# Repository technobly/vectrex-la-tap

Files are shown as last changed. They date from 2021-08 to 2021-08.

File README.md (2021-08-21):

Vectrex LA TAP
===

The Vectrex LA Tap is a logic analyzer tap for the Vectrex. It also turns the cartridge to face the player.  Use it for technical debugging, or just as a way to display your running cartridge. Populate either the right-angle or straight male header for connections, or both.  I prefer the right-angle to keep the jumpers lower to the table where your logic analyzer is located.  This can also be used as a quick way to add RAM to a game if you don't have a multicart like [VEXTREME](https://github.com/technobly/VEXTREME) that can do that for you programmatically.

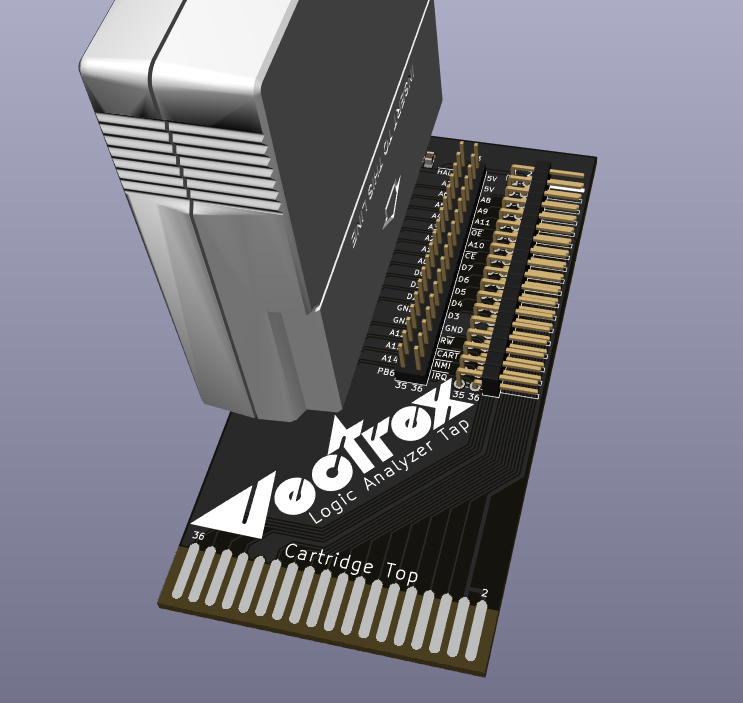
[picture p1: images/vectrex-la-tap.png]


See it in action here:
https://www.youtube.com/watch?v=Tel6ZxioI6E

BOM and Parts ordering
===

- 1x - 36-pin Edge Connector [AMP 5645235-4](https://www.digikey.com/en/products/detail/te-connectivity-amp-connectors/5645235-4/1122061)

Optional Components
- 1x - 36-pin 2.54 mm dual-row right-angle male header [PH2RA-36-UA](https://www.digikey.com/en/products/detail/adam-tech/PH2RA-36-UA/9830520)
- 1x - 36-pin 2.54 mm dual-row straight male header [PRPC018DAAN-RC](https://www.digikey.com/en/products/detail/sullins-connector-solutions/PRPC018DAAN-RC/2775276)
- 1x - [0.1uF 0805 capacitor](https://www.digikey.com/en/products/detail/avx-corporation/08055C104KAT2A/563505)

Ordering PCB's
===

OSHPark is a good place to order with purple or the new "after dark" theme color scheme.  You can upload the KiCad `vextrex-la-tap.kicad_pcb` there directly.  I would download this entire Github repo ZIP file first though instead of just trying to save the PCB file from your browser.

Another way to order PCB's is by using the included [gerbers](gerbers/vectrex-la-tap-v1.0.zip) and uploading those with all of the necessary specs to companies like [PCBWay](https://www.pcbway.com) or [JLCPCB](https://jlcpcb.com)

If you want to make it fancy, don't forget to make your board finish ENIG (gold flash) with a 45 degree chamfered edge.  I ended up making these really cheap with HASL finish since I won't be using them that frequently.

LICENSE
===

Creative Commons Attribution-ShareAlike 4.0 International (CC BY-SA 4.0) - essentially do whatever you want, and if this is helpful to you [consider buying me a coffee](https://buymeacoffee.com/walach)  Full [LICENSE here](LICENSE)

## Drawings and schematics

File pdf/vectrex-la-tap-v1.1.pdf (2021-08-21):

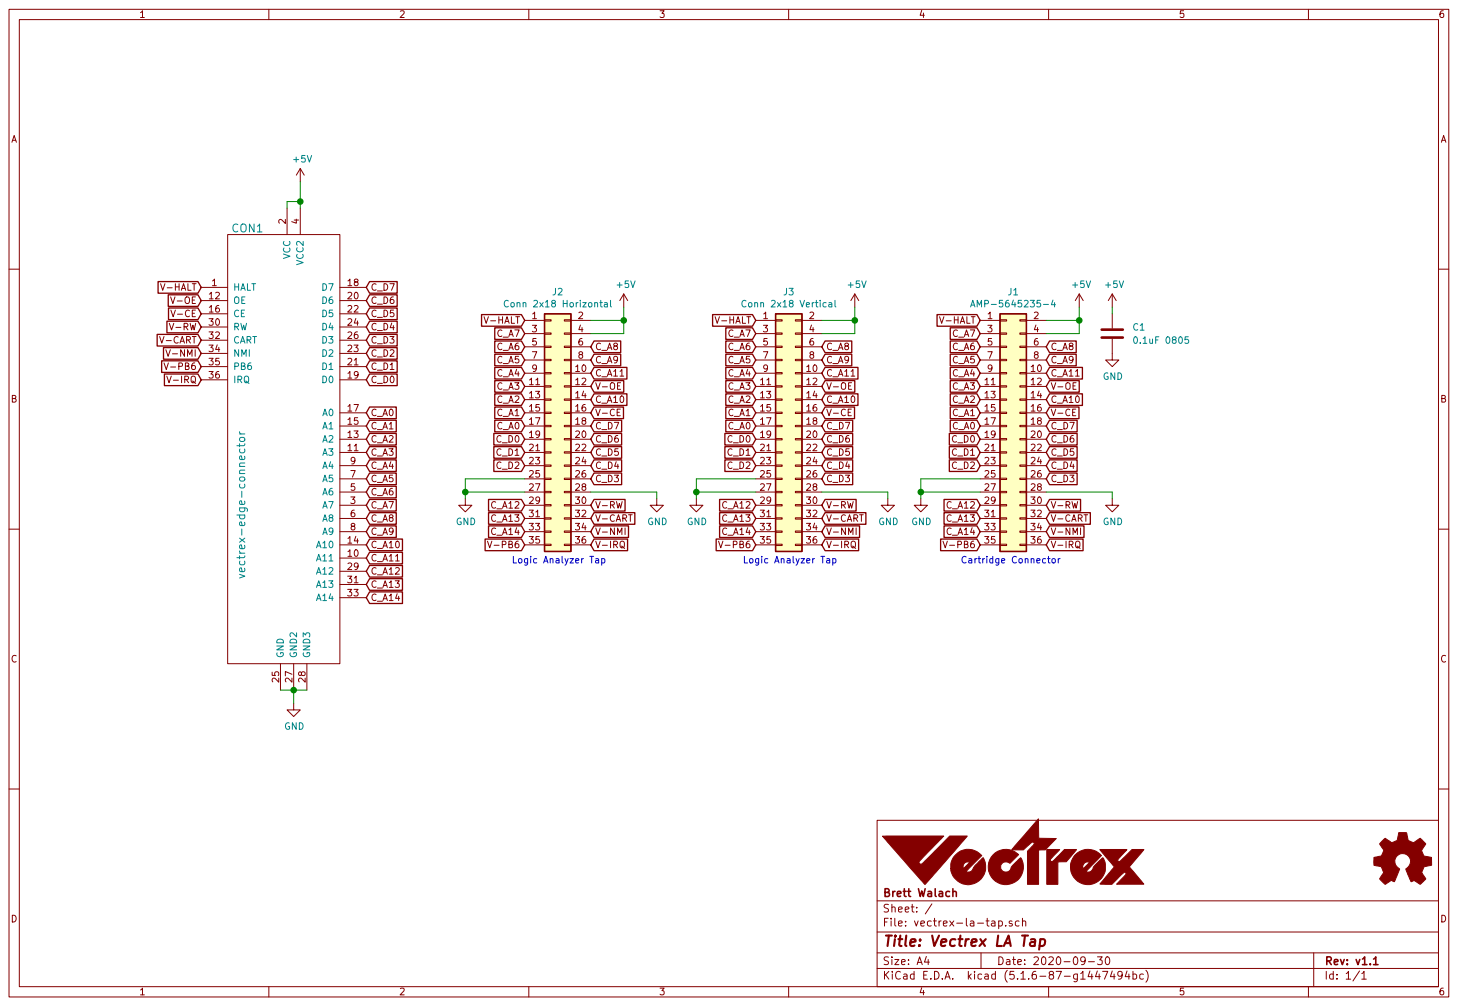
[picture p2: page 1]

4 A6 5 A8 6 A5 7 A9 8 A4 9 A11 10 D6 20 RW 30 A3 11 D1 21 A13 31 OE 12 D5 22 CART 32 A2 13 D2 23 A14 33 A10 14 D4 24 NMI 34 A1 15 GND 25 PB6 35 CE 16 D3 26

Id: 1/1 Title: Vectrex LA Tap

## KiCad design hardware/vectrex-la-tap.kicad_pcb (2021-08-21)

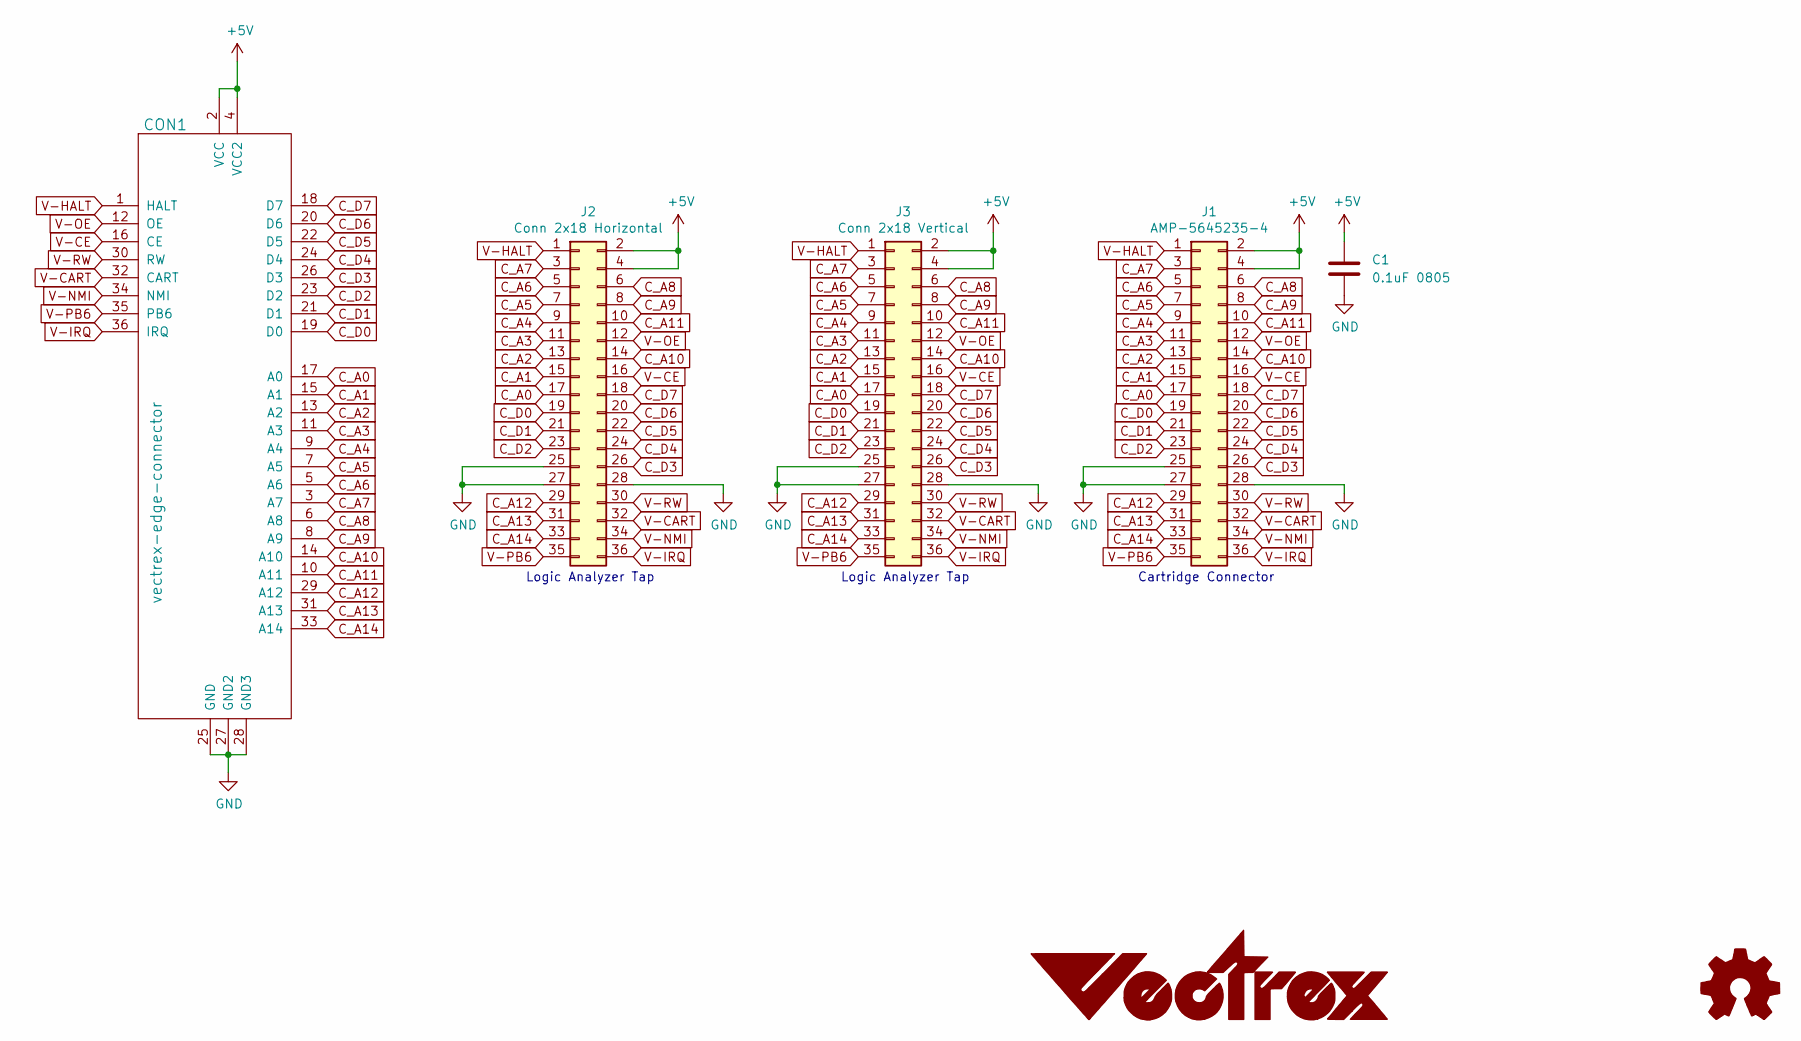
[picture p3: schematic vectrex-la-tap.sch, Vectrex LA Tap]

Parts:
C1: 0.1uF 0805; C_0805_2012Metric_Pad1.15x1.40mm_HandSolder
CON1: vectrex-edge-connector; vectrex-edge-connector-thinner-no-soldermask
G1: LOGO; vectrex-us-silkscreen
J1: AMP-5645235-4; AMP_5645235-4_2x18_P2.54mm_Vertical
J2: Conn 2x18 Horizontal; PinHeader_2x18_P2.54mm_Horizontal
J3: Conn 2x18 Vertical; PinHeader_2x18_P2.54mm_Vertical

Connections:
+5V: C1.1, CON1.2 (VCC), CON1.4 (VCC2), J1.2, J1.4, J2.2, J2.4, J3.2, J3.4
C_A0: CON1.17 (A0), J1.17, J2.17, J3.17
C_A1: CON1.15 (A1), J1.15, J2.15, J3.15
C_A2: CON1.13 (A2), J1.13, J2.13, J3.13
C_A3: CON1.11 (A3), J1.11, J2.11, J3.11
C_A4: CON1.9 (A4), J1.9, J2.9, J3.9
C_A5: CON1.7 (A5), J1.7, J2.7, J3.7
C_A6: CON1.5 (A6), J1.5, J2.5, J3.5
C_A7: CON1.3 (A7), J1.3, J2.3, J3.3
C_A8: CON1.6 (A8), J1.6, J2.6, J3.6
C_A9: CON1.8 (A9), J1.8, J2.8, J3.8
C_A10: CON1.14 (A10), J1.14, J2.14, J3.14
C_A11: CON1.10 (A11), J1.10, J2.10, J3.10
C_A12: CON1.29 (A12), J1.29, J2.29, J3.29
C_A13: CON1.31 (A13), J1.31, J2.31, J3.31
C_A14: CON1.33 (A14), J1.33, J2.33, J3.33
C_D0: CON1.19 (D0), J1.19, J2.19, J3.19
C_D1: CON1.21 (D1), J1.21, J2.21, J3.21
C_D2: CON1.23 (D2), J1.23, J2.23, J3.23
C_D3: CON1.26 (D3), J1.26, J2.26, J3.26
C_D4: CON1.24 (D4), J1.24, J2.24, J3.24
C_D5: CON1.22 (D5), J1.22, J2.22, J3.22
C_D6: CON1.20 (D6), J1.20, J2.20, J3.20
C_D7: CON1.18 (D7), J1.18, J2.18, J3.18
GND: C1.2, CON1.25 (GND), CON1.27 (GND2), CON1.28 (GND3), J1.25, J1.27, J1.28, J2.25, J2.27, J2.28, J3.25, J3.27, J3.28
V-CART: CON1.32 (CART), J1.32, J2.32, J3.32
V-CE: CON1.16 (CE), J1.16, J2.16, J3.16
V-HALT: CON1.1 (HALT), J1.1, J2.1, J3.1
V-IRQ: CON1.36 (IRQ), J1.36, J2.36, J3.36
V-NMI: CON1.34 (NMI), J1.34, J2.34, J3.34
V-OE: CON1.12 (OE), J1.12, J2.12, J3.12
V-PB6: CON1.35 (PB6), J1.35, J2.35, J3.35
V-RW: CON1.30 (RW), J1.30, J2.30, J3.30

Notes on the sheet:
Cartridge Connector
Logic Analyzer Tap

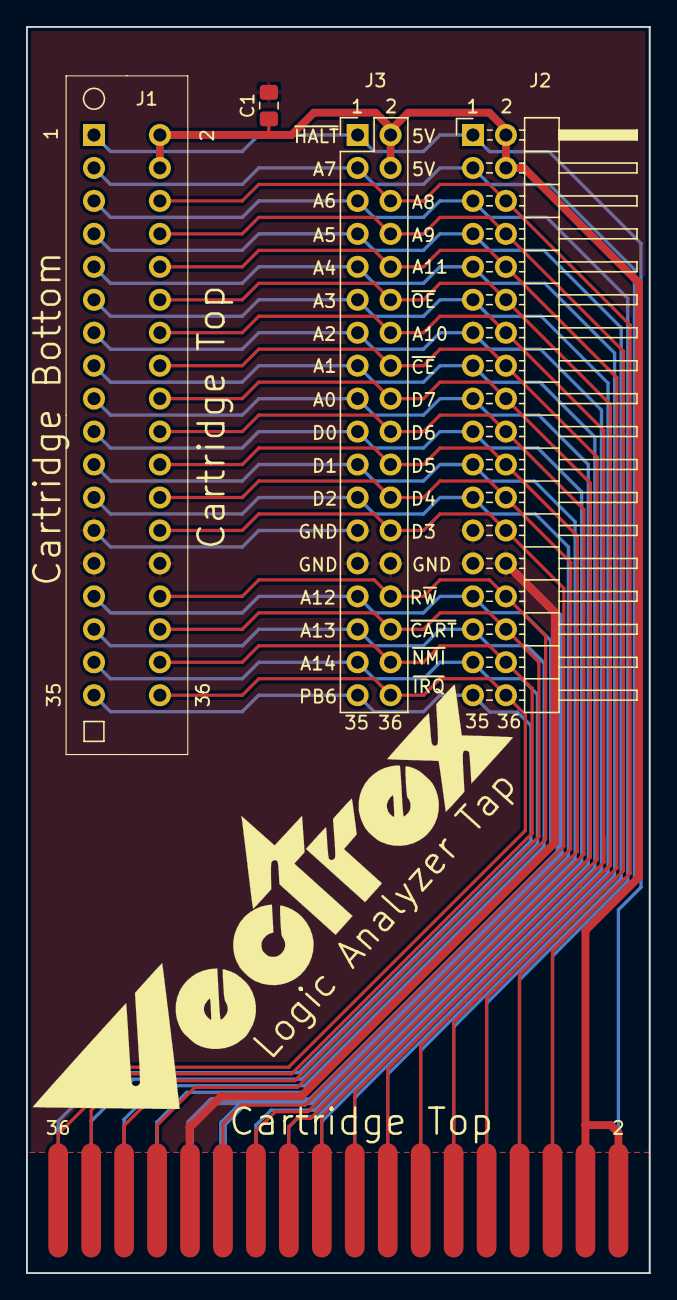
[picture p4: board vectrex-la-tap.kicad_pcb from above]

Board: 2 copper layers, 48.0 x 96.1 mm, 6 parts (0 on the bottom side), 33 nets.
